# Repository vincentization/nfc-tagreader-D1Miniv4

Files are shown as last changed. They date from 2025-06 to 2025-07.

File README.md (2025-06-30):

# Tag Reader for Home Assistant
This is based on the fantastic [tagreader](https://github.com/adonno/tagreader) project by adonno.

More Documentation can be found there as well.

---

My version focuses on the usage of this device as an alarm controller for Homeassistant using the [Alarmo](https://github.com/nielsfaber/alarmo) plugin. My tagreader basically only does this:
- arm/disarm alarm in Homeassistant (Alarmo) using NFC keychain tags
- show the current alarm state using the LED
- write NDEF data on new NFC tags

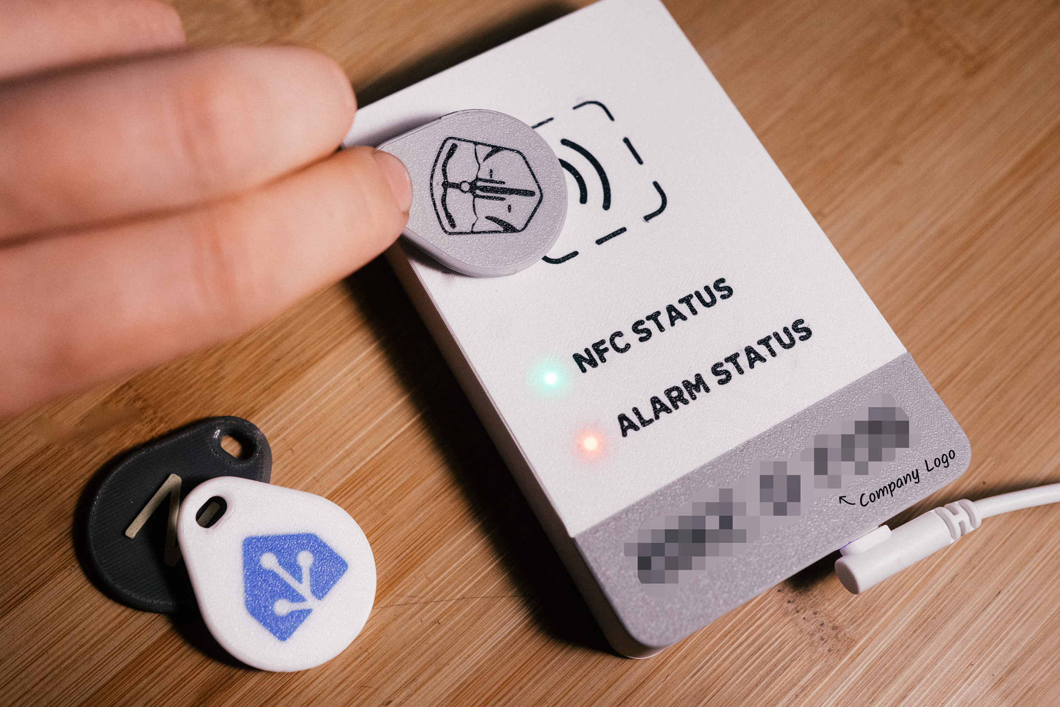
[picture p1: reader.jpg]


## What I changed:
YAML:
- added second LED for showing alarm state
- added a few light effects for showing states
- added a sensor to fetch current alarm state in Homeassistant
- removed all music related stuff
- removed all buzzer signals

Case:
- made it bigger to have more space for labels/logos
- added a second LED
- added heat set inserts
- added transparent LED channels

## Components
I used the following components:

 - ESP8266 D1 Mini v4.0
 - PN532 NFC Reader v4 (v4 has extended reach, otherwise won't work behind thick windows)
 - 2x WS2812 SMD 5050 Leds

### Connecting the components
> [!IMPORTANT]  
> I used the v4 version of the ESP8266 D1 Mini which has a slightly different pinout than its predecessor.

My wiring can be seen here:

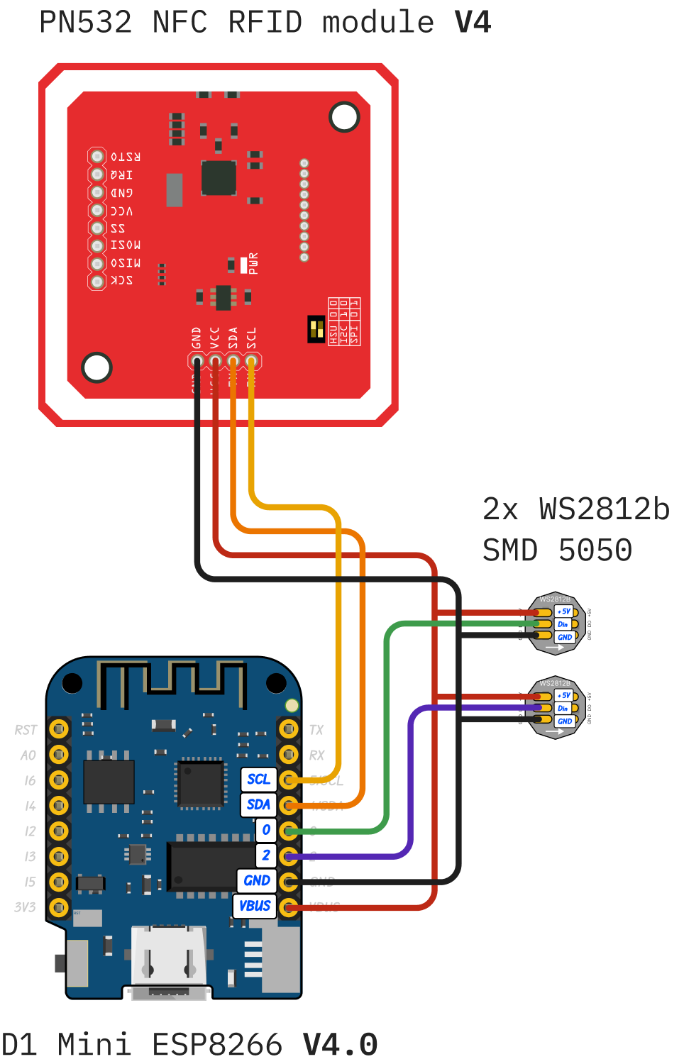
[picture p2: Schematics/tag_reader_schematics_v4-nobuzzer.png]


Switches on PN532 need to be set to I2C mode:
- Switch 1: On (up)
- Switch 2: Off (down)

To flash the reader firmware to your D1 Mini you point ESPHome at [tagreader.yaml](tagreader.yaml).  

## Case
made some changes to the original case design. Mainly did that to house the second LED and have some more space at the front of the case for labels and logos.

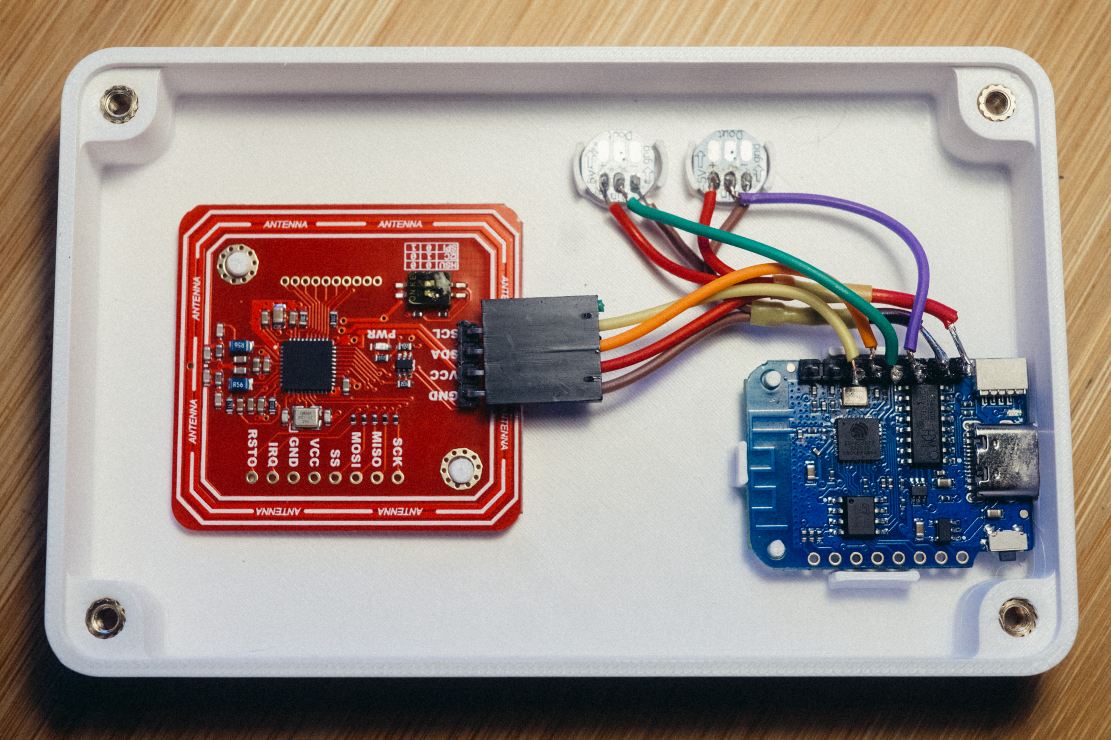
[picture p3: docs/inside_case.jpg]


Step File from Fusion are [here](/CAD%20Files/)

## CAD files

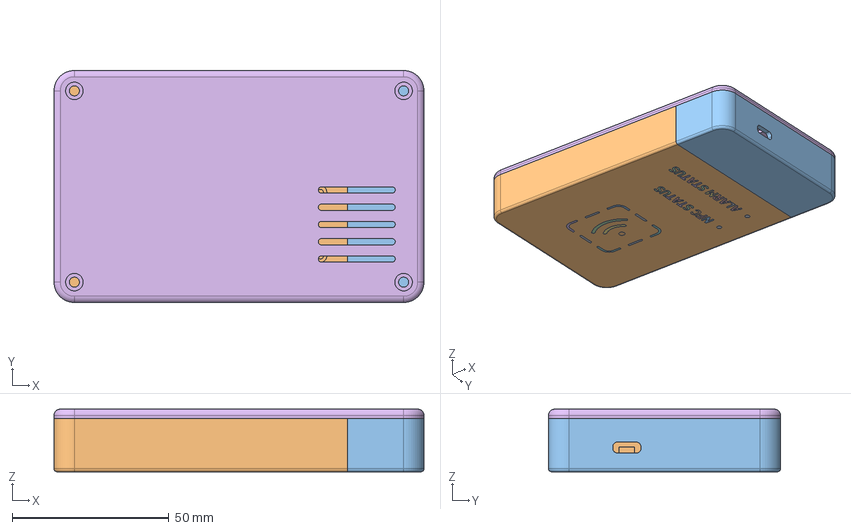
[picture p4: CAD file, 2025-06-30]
CAD Files/NFC Tagreader Nologo v2.step
118.0 x 74.0 x 20.0 mm
transparent
Lid

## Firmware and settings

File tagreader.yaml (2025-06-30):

wifi:
  networks:
    - ssid: !secret wifi_ssid          # Enter your WiFi SSID here. Example: `ssid: 'your_network_name'`
      password: !secret wifi_password      # Enter your wifi password here. Example: `password: 'abcde123456'`
  ap:
    ssid: ${name}

esp8266:
  board: d1_mini

substitutions:
  name: tagreader1
  friendly_name: TagReader 1

dashboard_import:
  package_import_url: github://adonno/tagreader/tagreader.yaml

esphome:
  name: ${name}
  friendly_name: ${friendly_name}
  name_add_mac_suffix: false
  
  project:
    name: adonno.tag_reader
    version: dev

  on_boot:
    priority: -10
    then:
    - wait_until:
        api.connected:
    - logger.log: API is connected!
    - light.turn_on:
        id: nfc_led
        brightness: 100%
        red: 0%
        green: 0%
        blue: 100%
        flash_length: 500ms
    - switch.turn_on: nfc_led_enabled
    - switch.turn_on: alarm_led_enabled
    - delay: 2s
    - light.turn_on:
        id: alarm_led
    - script.execute: update_leds


text_sensor:
  - platform: version
    hide_timestamp: true
    name: "${friendly_name} ESPHome Version"
    entity_category: diagnostic
  - platform: wifi_info
    ip_address:
      name: "${friendly_name} IP Address"
      icon: mdi:wifi
      entity_category: diagnostic
    ssid:
      name: "${friendly_name} Connected SSID"
      icon: mdi:wifi-strength-2
      entity_category: diagnostic
  - platform: homeassistant
    id: alarm_state
    entity_id: alarm_control_panel.alarmo
    on_value:
      then:
        - light.turn_on:
            id: alarm_led
        - switch.turn_on: alarm_led_enabled
        - script.execute: update_leds

# Define switches to control LED and buzzer from HA
switch:
- platform: template
  name: "${friendly_name} NFC Status LED enabled"
  id: nfc_led_enabled
  icon: mdi:alarm-light-outline
  optimistic: true
  restore_mode: RESTORE_DEFAULT_ON
  entity_category: config
- platform: template
  name: "${friendly_name} Alarm Status LED enabled"
  id: alarm_led_enabled
  icon: mdi:alarm-light-outline
  optimistic: true
  restore_mode: RESTORE_DEFAULT_ON
  entity_category: config
- platform: template
  name: "Enable Unknown Tag Scanning"
  id: unknown_tag_enabled
  optimistic: true
  restore_mode: RESTORE_DEFAULT_OFF
  entity_category: config

# Define buttons for writing tags via HA
button:
  - platform: template
    name: Write Tag Random
    id: write_tag_random
    # Optional variables:
    icon: "mdi:pencil-box"
    on_press:
      then:
      - light.turn_on:
          id: nfc_led
          brightness: 100%
          red: 100%
          green: 0%
          blue: 100%
      - lambda: |-
          static const char alphanum[] = "0123456789abcdef";
          std::string uri = "https://www.home-assistant.io/tag/";
          for (int i = 0; i < 8; i++)
            uri += alphanum[random_uint32() % (sizeof(alphanum) - 1)];
          uri += "-";
          for (int j = 0; j < 3; j++) {
            for (int i = 0; i < 4; i++)
              uri += alphanum[random_uint32() % (sizeof(alphanum) - 1)];
            uri += "-";
          }
          for (int i = 0; i < 12; i++)
            uri += alphanum[random_uint32() % (sizeof(alphanum) - 1)];
          auto message = new nfc::NdefMessage();
          message->add_uri_record(uri);
          ESP_LOGD("tagreader", "Writing payload: %s", uri.c_str());
          id(pn532_board).write_mode(message);
      - wait_until:
          not:
            pn532.is_writing:
      - light.turn_off:
          id: nfc_led
  - platform: template
    name: Clean Tag
    id: clean_tag
    icon: "mdi:nfc-variant-off"
    on_press:
      then:
      - light.turn_on:
          id: nfc_led
          brightness: 100%
          red: 100%
          green: 64.7%
          blue: 0%
      - lambda: 'id(pn532_board).clean_mode();'
      - wait_until:
          not:
            pn532.is_writing:
      - light.turn_off:
          id: nfc_led
  - platform: template
    name: Cancel writing
    id: cancel_writing
    icon: "mdi:pencil-off"
    on_press:
      then:
      - lambda: 'id(pn532_board).read_mode();'
      - light.turn_off:
          id: nfc_led

  - platform: restart
    name: "${friendly_name} Restart"
    entity_category: config

# Enable logging
logger:
  # level: VERY_VERBOSE
  # level: VERBOSE

# Enable Home Assistant API
api:
  services:

  - service: write_tag_id
    variables:
      tag_id: string
    then:
    - light.turn_on:
        id: nfc_led
        brightness: 100%
        red: 100%
        green: 0%
        blue: 0%
    - lambda: |-
        auto message = new nfc::NdefMessage();
        std::string uri = "https://www.home-assistant.io/tag/";
        uri += tag_id;
        message->add_uri_record(uri);
        id(pn532_board).write_mode(message);
    - wait_until:
        not:
          pn532.is_writing:
    - light.turn_off:
        id: nfc_led

# Enable OTA upgrade
ota:
  - platform: esphome

i2c:
  scan: False
  frequency: 400kHz
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

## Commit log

2025-06-30 initial changes
    [Case-2.stl, Cover-circles_horizontal.stl, Cover-circles_no_logo.stl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]
2025-07-14 fixed wiring schematic error /u/OldRemote111 pointed out on reddit
2025-07-15 fixed switch order in schematic
